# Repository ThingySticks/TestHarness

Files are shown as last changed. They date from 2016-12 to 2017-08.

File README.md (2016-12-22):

ThingySticks Test Harness
=========================

Particle Electron based test harness to test Photon based ThingyStick sticks.
Most pins of the Photon are taken to the Electron's matching pin (except VIn,  VBatt and RST).
e.g. D7 on Photon board Pogo Pins will connect to D7 on the Electron.

Board Under Test location is intended to be populated with Pogo pins or another connector system to match up with the Board Under Tests photon pads/socket.

Board under Test should not have a photon fitted.

Electron Pinout: https://docs.particle.io/assets/images/electron/illustrations/electron_pinout.pdf

Improvements for V2.1
---------------------

* 10k Pull down resistors for Q1 and Q2 relay drive FETs to prevent them oscilating when not connected.
* Add a button to start the test (e.g. Use C4).
* Add high side current monitor so PCB can be tested for shorts.
* Make use of I2C(2) on the Electrons C4/C5 pins (needs VIn relay to be driven from a different pin - maybe C0 - with a jumper so it can be disabled).
** Use full for current monitor
* B5,4 or 3 to measure voltage at VIn so that the USB power connection can be simulated (low priority).
* Diode on VIn from Electron so we don't try and power the relays and back feed the 5V regulator when running on USB or battery only.

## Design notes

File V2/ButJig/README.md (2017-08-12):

Cura Settings:

Profile: Fast Print

Modified as...
Layer Height: 0.2mm
Infil: 12
Adhesion: Skirt

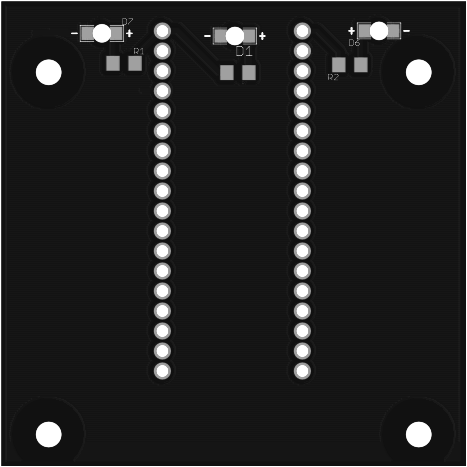
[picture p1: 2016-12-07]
V2/Images/TopBoard-bottom.png

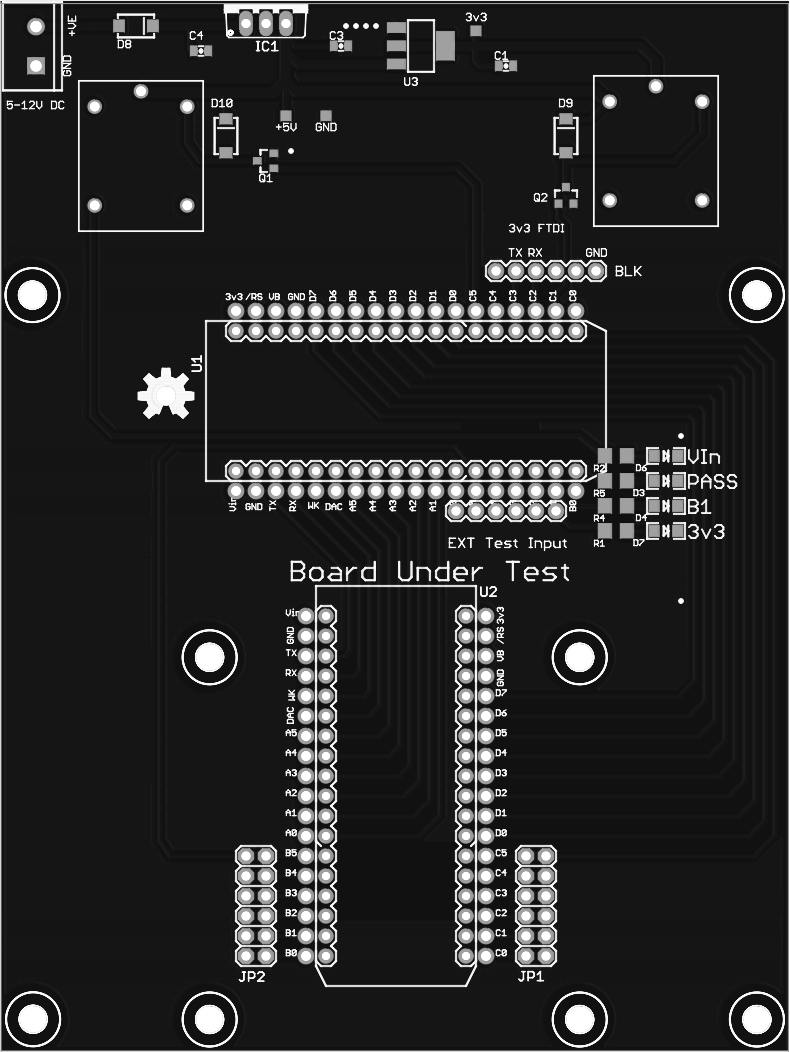
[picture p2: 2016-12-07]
V2/Images/BaseBoard-top.png

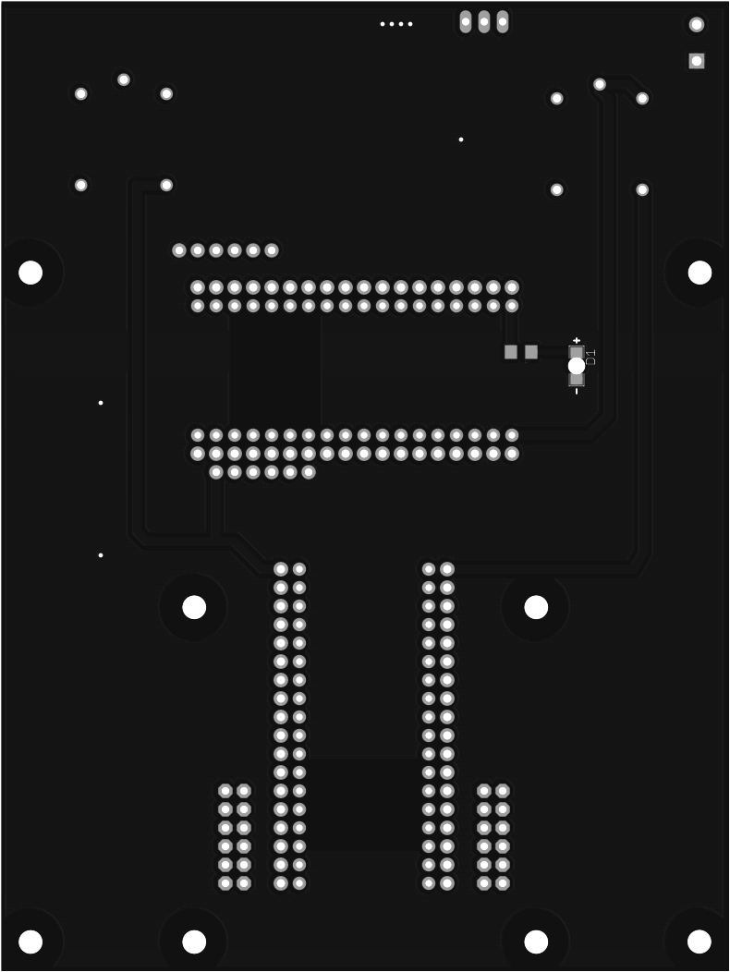
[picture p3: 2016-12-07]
V2/Images/BaseBoard-bottom.png

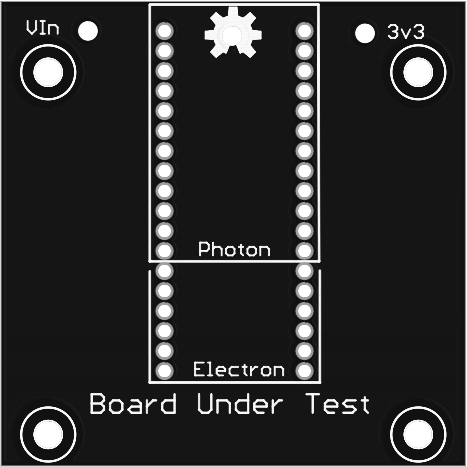
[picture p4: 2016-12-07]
V2/Images/TopBoard-top.png

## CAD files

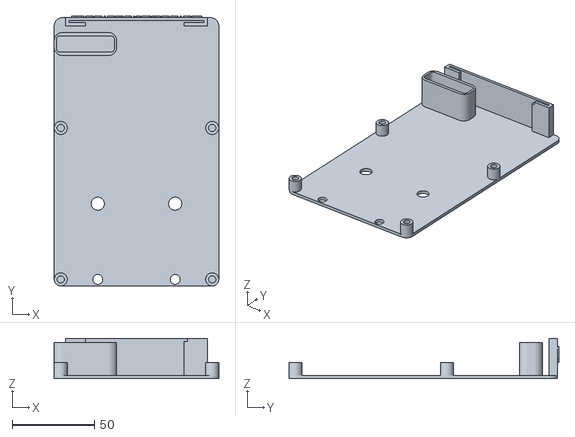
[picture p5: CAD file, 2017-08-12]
V2/ButJig/Base/JigBase.stl
100.0 x 164.0 x 24.4

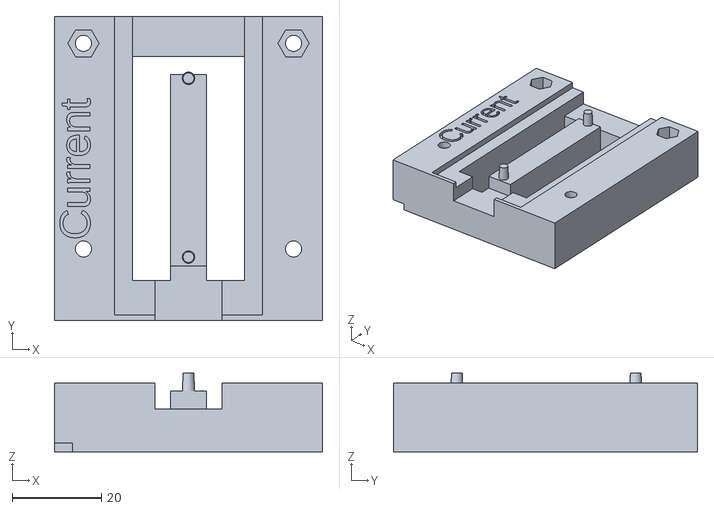
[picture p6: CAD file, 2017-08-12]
V2/ButJig/CurrentMonitor-Base.stl
60.0 x 68.0 x 17.6

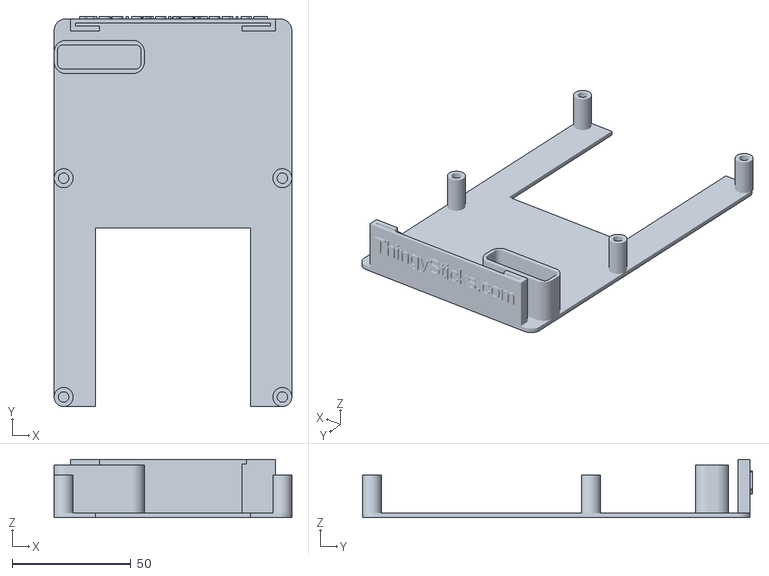
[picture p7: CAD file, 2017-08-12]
V2/ButJig/Base/JigBase-UnderMountingBoard.stl
100.0 x 164.0 x 24.4

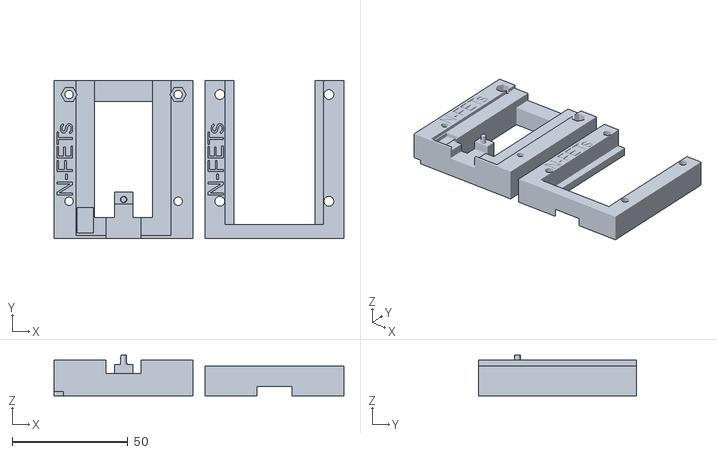
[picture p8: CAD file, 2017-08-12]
V2/ButJig/Quad-N-Fets.stl
125.0 x 68.0 x 17.6

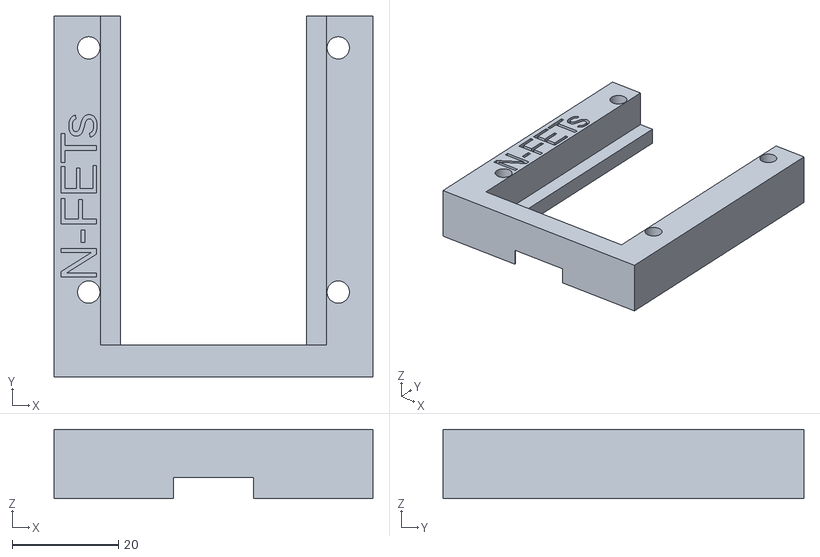
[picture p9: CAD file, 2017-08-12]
V2/ButJig/Quad-N-Fets-PushDown.stl
60.0 x 68.0 x 13.0

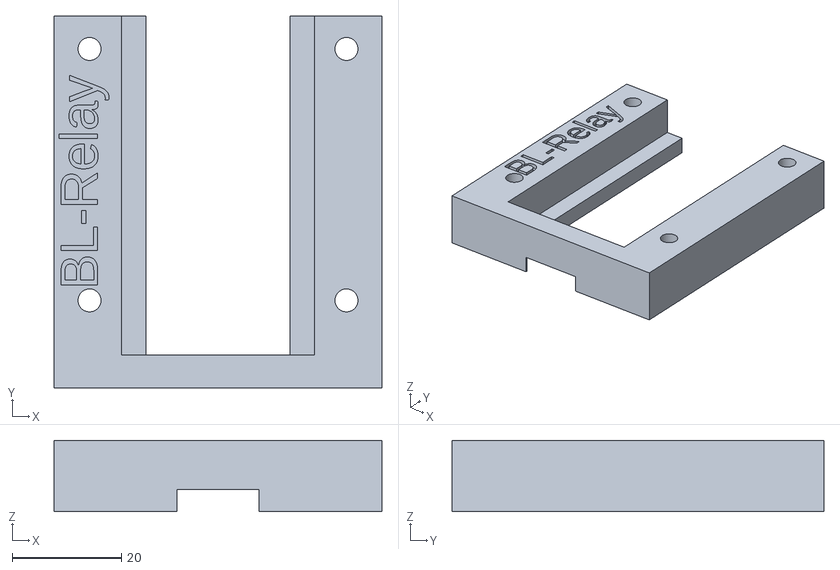
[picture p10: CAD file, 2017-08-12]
V2/ButJig/BigLatchingRelay-PushDown.stl
60.0 x 68.0 x 13.0

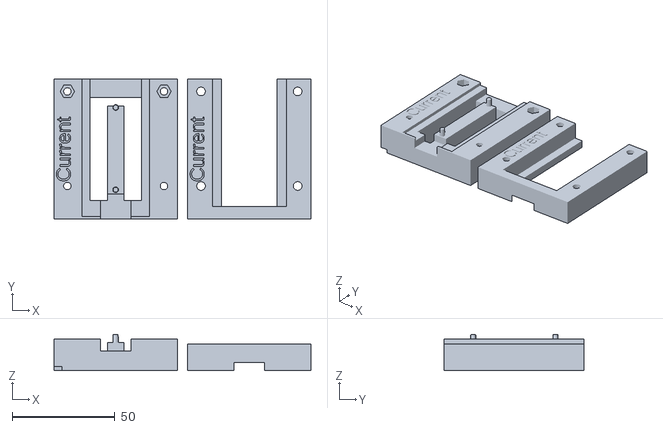
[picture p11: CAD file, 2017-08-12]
V2/ButJig/CurrentMonitor.stl
125.0 x 68.0 x 17.6

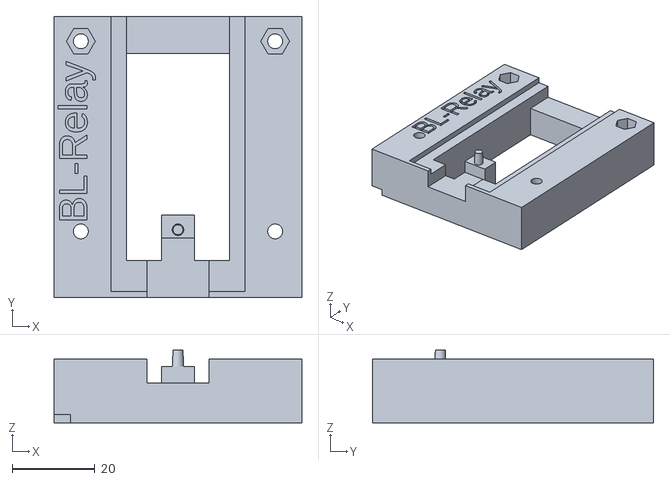
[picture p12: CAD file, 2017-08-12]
V2/ButJig/BigLatchingRelay-Base.stl
60.0 x 68.0 x 17.6

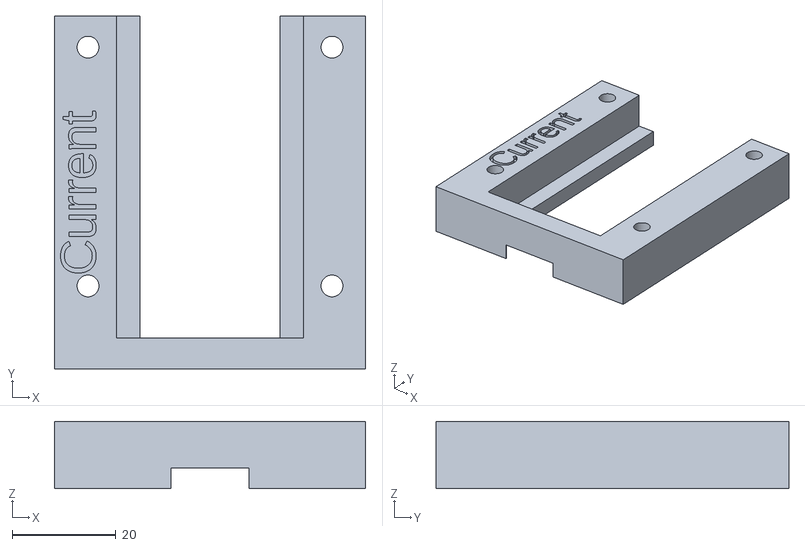
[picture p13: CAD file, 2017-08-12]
V2/ButJig/CurrentMonitor-PushDown.stl
60.0 x 68.0 x 13.0

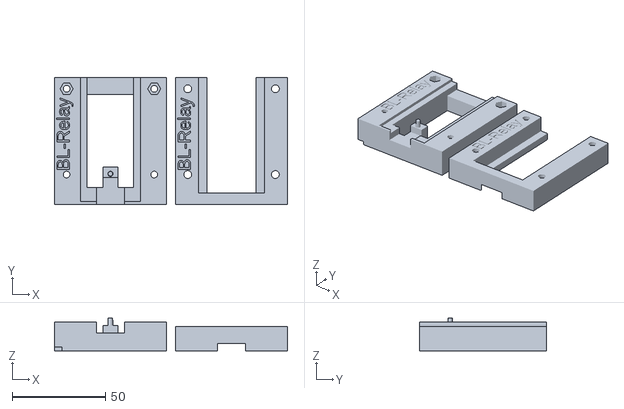
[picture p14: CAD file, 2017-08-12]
V2/ButJig/BigLatchingRelay.stl
125.0 x 68.0 x 17.6

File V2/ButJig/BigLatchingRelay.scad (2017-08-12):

buildBase = true;
buildPushDown = true;
showModels = true;

////////////////////////////////////////////////////////////////////
// Thermocouple PCB
// -----------------------------------------------------------------
// Device under test properties.
pin1ToPcbEdge =  8.3;
pcbPinOffset = 13.96;
pcbPin2Offset = 13.96;
pcbWidth = 31.31; //mm
pcbLength = 99.04;
pcbSupportBarLength = 20;
textLabel = "BL-Relay";

// TODO: Change this for the actual position.
oshLedXCutout = 0;
oshLedYCutout = 0; 
oshLedLength = 0;  // y axis.
oshLedWidth = 0; 
oshLedDepth = 0; 

showThermocouplePcb = true;
showQuadFetsPcb = false;
showEnvironmentV2Pcb = false;

include <ButJig.scad>;

module buildModel() {
    // Pcb
    cube([31.31,99.04,1.6]);
    
    // Move to the middle of the PCB.
    // Move down slightly to bring the markers though 
    // the 
    translate([31.31/2, 0, -4]) {
        // Mount pin 1
        translate([0,13.96,0]) {
            cylinder(d=3, h=20);
        }
        
        // Mount pin 2
        translate([0, 13.96,0]) {
            cylinder(d=3, h=20);
        }
        
        // Pin 1 marker.
        translate([8.89,8.3,0]) {
            cylinder(d=1, h=10);
        }
        
        // USB Plug
        // Z should be at the bottom of the PCB (1.6mm thick)
        // X is 1/2 width back from center
        // y is 15 back and 5 onto PCB
        translate([-(12/2),-15 + 5,4 - 1.6]) {
            cube([12, 20, 5]);
        }
    }
}

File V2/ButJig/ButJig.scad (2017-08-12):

// Base class for all the test jigs

// Critical measurements:
// Top left mount hole (with DUT vertical) is key alignment hole.
// Pin 1 X Offset from key hole = 14.78mm
// Pin 1 Y offset from key hole = 5.25mm (towards 0)
 
$fn=80;
cubeWidth = 60;
// Max length to make the cube.
// PCB may go past the end of it.
cubeLength = 68; //68;
bodyHeight = 18;


// FIXED (due to Pogo pins height).
// PCB needs to be at 13.5mm high for the pogo pins to make best contact.
pcbZPosition = 13.6;

// Make it a little higher so that the PCB can 
// be pressed level with the jig top
// but keep the POGO pins slightly compressed
bodyHeight = 15.4; // pcbZPosition + 1.6; // PCB depth


// Fixed. the Y distance from pin 1 Pogo pin to the first 
// mounting hole for the jig.
// How far infront of Pin1 the mounting hole is.
// Thsi should never change (pin 1 and mounting block hole never move).
// How far infront of Pin1 the mounting hole is.
pin1ToMountingHoleDistance =  5.25;

usbPlugWidth = 15;

// Mounting holes for us are 47mm across.
// 60 - 47 = 13 
// 13/2 = 6.5
holesXOffset = (60-47) / 2;
// How far down the block the mounting holes for the block are.
// 16mm is about the maximum that can be used without modifying the mounting block.
holesYOffset = 16; // 16mm gap between ext test input and top hole.

// The position of pin one on the test fixture
// this is constant
pin1Position = holesYOffset - pin1ToMountingHoleDistance;  

////////////////////////////////////////////////////////////////////
// Test Fixture properties.
// Board specific
////////////////////////////////////////////////////////////////////
// Will be in subclass file

/////////////////////////////////////////////////////////////////////
// Position of the PCB front edge
// Computed from the specified distance of pin 1 to the pcb edge.
frontEdgePosition = pin1Position - pin1ToPcbEdge;
echo ("frontEdgePosition:", frontEdgePosition);

/////////////////////////////////////////////////////////////////////

// Cut out for the 3v3 resistor on the test rig PCB
module boardResistorCutout() {
    cube([4,4,2]);
}

// block mounting hole is holesYOffset mm from the front edge.
module pcbCutout() {
        
// Work back from the computed Pin 1 Position to find where the 
// edge of the PCB should be.
xOffset = (cubeWidth - pcbWidth)/2;

    // add 2mm tollerance to the front/rear position of the PCB
    // as the finish may be rough and mounting pins are the most critical
    // And add 0.5mm either size for PCB width tollerance
    translate([xOffset-0.5, frontEdgePosition -1 , pcbZPosition]) {
       cube([pcbWidth+1, pcbLength + 2, bodyHeight - pcbZPosition + 0.01]);
    }
    
    // OSH LED on Thermocouple PCB
    translate([xOffset + oshLedXCutout, 
    frontEdgePosition + oshLedYCutout, 
    pcbZPosition-oshLedDepth]) {
        cube([oshLedWidth, oshLedLength, oshLedDepth+0.1]);
    }
    
    // Cutout at the end
    leftCutout = (cubeWidth - 25)/2;
    translate([leftCutout, 55, pcbZPosition -4]) {
        cube([25, cubeLength-55+0.1, 4.1]);
    }
}

// block mounting hole is holesYOffset mm from the front edge.
module pcbPin(offset) {
    
xOffset = (cubeWidth /2);
yPosition = frontEdgePosition + offset;
    
echo ("Offset:", offset);
echo ("yPosition:",yPosition);
echo ("pcbZPosition:",pcbZPosition);
    
    translate([xOffset, yPosition, pcbZPosition]) {
        cylinder(d1=2.8, d2=2.4, h=4);
    }
}

// Cut out a section to allow for a USB plug to have
// been soldered to the PCB.
module usbConnectorCutout() {
    
echo("USB pcbPinOffset: ", pcbPinOffset);
pinPosition = frontEdgePosition + pcbPinOffset;
    
    translate([(cubeWidth - usbPlugWidth)/2, 0, pcbZPosition-4]) {
        // Go most of the way to the first PCB pin.
        cube([usbPlugWidth, pinPosition -2, 8]);
    }
}

module pogoPinsCutout() {
    cube([25, 50, 20]);
}

module mountHole(x,y, nutUnder, nutOnTop, holeDiameter) {
nutHoleDiameter = 7;
    translate([x,y,0]) {
        
        // Hollow out the main screw thread all the way up.
        translate([0,0,-0.1]) {
            cylinder(d=holeDiameter, h=bodyHeight+2);
        }
            
        // If their is a nut underneath this (i.e. screw fixed to PCB)
        if (nutUnder) {
            cylinder(d=nutHoleDiameter, h=4);
        
            translate([0,0,4]) {
                cylinder(d1=nutHoleDiameter,d2=holeDiameter, h=10);
            }
        }
        
        if (nutOnTop) {
            translate([0,0,bodyHeight - 4]) {
                // Make it hex to hold the nut
                cylinder(d=7, h=4 + 0.3, $fn=6);
            }
        }
    }
}

module mountHoles() {
    // Across = 47mm.
    // Down = 46mm.
    
holeDiameter = 3.6;
    
    
    mountHole(0,0, true, false, holeDiameter);
    // This pin is key pin with 0 offset all around?
    mountHole(47,0, true, false, holeDiameter);
    mountHole(0,46, false, true, holeDiameter);
    mountHole(47,46, false, true, holeDiameter);
}


module addText(zPosition, height) {
    translate([8,18,zPosition]) {
        rotate([0,0,90]) {
            linear_extrude(h=height) {
                #text(textLabel, size=7);
            }
        }
    }
}

module mainBody(holesXOffset) {
    difference() {
        union() {
            color("blue") {
                cube([cubeWidth, cubeLength, bodyHeight]);
            }
        }
        union() {
            // Move 5 + (4/2) mm down for the hole.
            translate([holesXOffset,holesYOffset,-0.1]) {
                mountHoles();
            }
            
            // 14mm wide. so 7mm back from center.
            translate([30-(25/2),holesYOffset - 7,-0.1]) {
                pogoPinsCutout();
            }
            
            pcbCutout(holesYOffset);
            
            // 0,0 position their is a resistor on the main
            // PCB (for 3v3 LED), need to nibble out a little from that corner
            // to prevent it clashing
            boardResistorCutout();
            
            addText(bodyHeight-1, 1);            
        }
    }
}

module body() {
   
// Pin 1 is 5.25mm from (top hole?) - smaller y.
    // pin1ToMountingHoleDistance
    
    // show pin 1
    translate([47 + holesXOffset - 14.78 ,holesYOffset  - pin1ToMountingHoleDistance,0]) {
       // cylinder(d=1, h=15);
    }
    
    
    difference() {
        union() {
            mainBody(holesXOffset);
            // Fill in the middle bit to allow for a support pin
            translate([(cubeWidth / 2) -4, 0, 0]) {
                color("green") {
                    cube([8, pcbSupportBarLength, pcbZPosition]);
                }
            }
        } 
        union() {
            usbConnectorCutout();
        }
    }
    
    // Add a vertical pin to locate the PCB onto the jig.
    pcbPin(pcbPinOffset);
    // Some boards have a second pin.
    pcbPin(pcbPin2Offset);
    
    translate([0,0,0]) {
        // pin1Marker();
    }
}

module pressDownTool() {
    
height = 13; // Should just cover full height of the bolts
holesXOffset = (60-47) / 2;
// How far down the block the mounting holes for the block are.
// 16mm is about the maximum that can be used without modifying the mounting block.
holesYOffset = 16; // 16mm gap between ext test input and top hole.
holeDiameter = 4.2; // larger than the base
    
    difference() {
        union() {
            color("pink") {
                cube([cubeWidth, cubeLength, height]);
            }
        }
        union() {
            addText(height-1, 1);
            
            translate([holesXOffset,holesYOffset,-0.1]) {
                    mountHole(0,0, false, false, holeDiameter);
                    // This pin is key pin with 0 offset all around?
                    mountHole(47,0, false, false, holeDiameter);
                    mountHole(0,46, false, false, holeDiameter);
                    mountHole(47,46, false, false, holeDiameter);
            }
            
            // Cut out the entire inside for pcb - 5mm (2.5mm either size)
            
             
            // The position of pin one on the test fixture
            // this is constant
            pin1Position = holesYOffset - pin1ToMountingHoleDistance;    

            // Work back from the computed Pin 1 Position to find where the 
            // edge of the PCB should be.
            frontEdgePosition = pin1Position - pin1ToPcbEdge;
            xOffset = (cubeWidth - pcbWidth)/2;
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

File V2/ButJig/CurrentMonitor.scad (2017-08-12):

buildBase = true;
buildPushDown = true;
showModels = true;

////////////////////////////////////////////////////////////////////
// Environment V2
// -----------------------------------------------------------------
// Device under test properties.
pin1ToPcbEdge =  8.57;
pcbPinOffset = 12.00;
pcbPin2Offset = 52.00;
pcbWidth = 32; // 31.75; //mm on X Axis.
pcbLength = 90; // on Y Axis.
// Lenfth of the middle bar with the pins on
pcbSupportBarLength = 55;
textLabel = "Current";

oshLedXCutout = 0;
oshLedYCutout = 0; 
oshLedLength = 11;  // y axis.
oshLedWidth = 7; 
oshLedDepth = 0; 

include <ButJig.scad>;


module buildModel() {
    // Pcb
    // Don't use variables above as they may need to be 
    // fudged to give suitable tollerances.
    cube([32,90,1.6]);
    
    // Move to the middle of the PCB.
    // Move down slightly to bring the markers though 
    // the 
    translate([32/2, 0,-4]) {
        // First mounting hole
        translate([0,12,0]) {
            cylinder(d=3, h=20);
        }
        
        // Second mounting hole
        translate([0, 12+40,0]) {
            cylinder(d=3, h=20);
        }
        
        // Pin 1 marker.
        translate([7,8.57,0]) {
            cylinder(d=1, h=10);
        }
        
        // USB Plug
        // Z should be at the bottom of the PCB (1.6mm thick)
        // X is 1/2 width back from center
        // y is 15 back and 5 onto PCB
        translate([-(12/2),-15 + 5,4 - 1.6]) {
            cube([12, 20, 5]);
        }
    }
}

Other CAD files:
V2/ButJig/EnvironmentV2-Base.stl
V2/ButJig/Thermocouple.stl
V2/ButJig/EnvironmentV2.stl
V2/ButJig/Thermocouple-Base.stl
V2/ButJig/Thermocouple-PushDown.stl
V2/ButJig/Quad-N-Fets-Base.stl
V2/ButJig/EnvironmentV2-PushDown.stl
V2/ButJig/EnvironmentV2.scad
V2/ButJig/Base/JigBase.scad
V2/ButJig/Quad-N-Fets.scad
V2/ButJig/Thermocouple.scad

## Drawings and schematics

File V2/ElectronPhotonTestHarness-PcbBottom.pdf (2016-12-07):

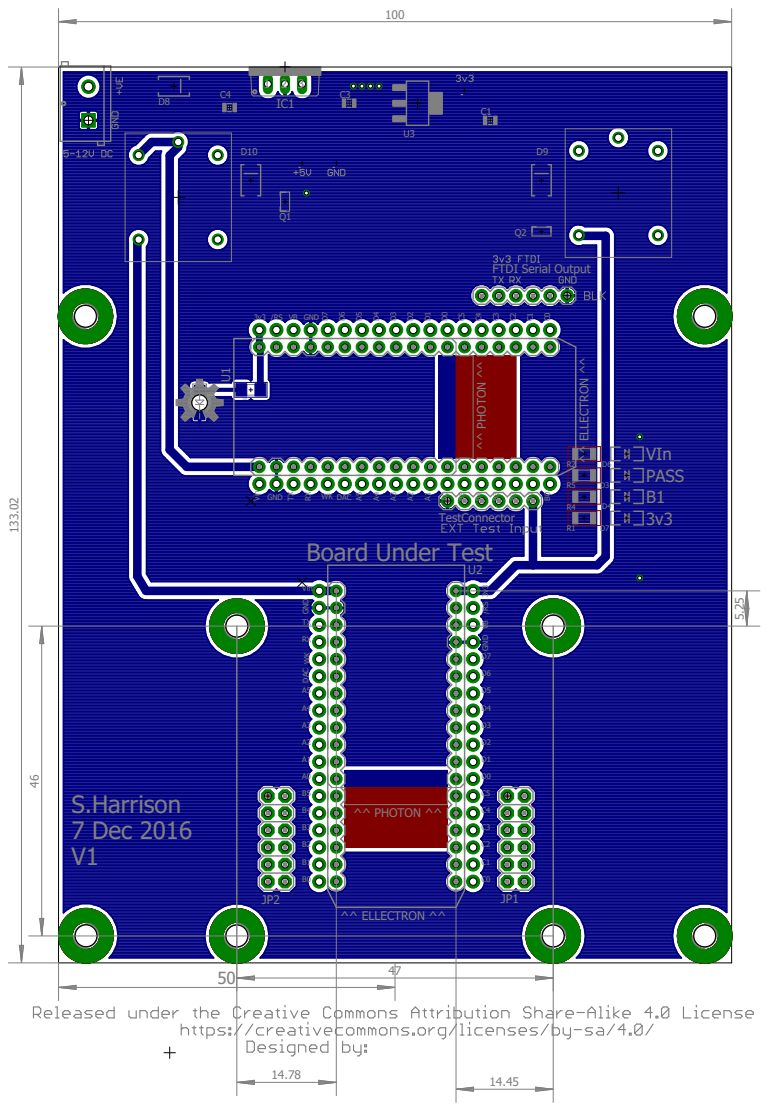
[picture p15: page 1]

VIn Board Under Test

R2R4R5 | PASS

TestConnector | 3v3

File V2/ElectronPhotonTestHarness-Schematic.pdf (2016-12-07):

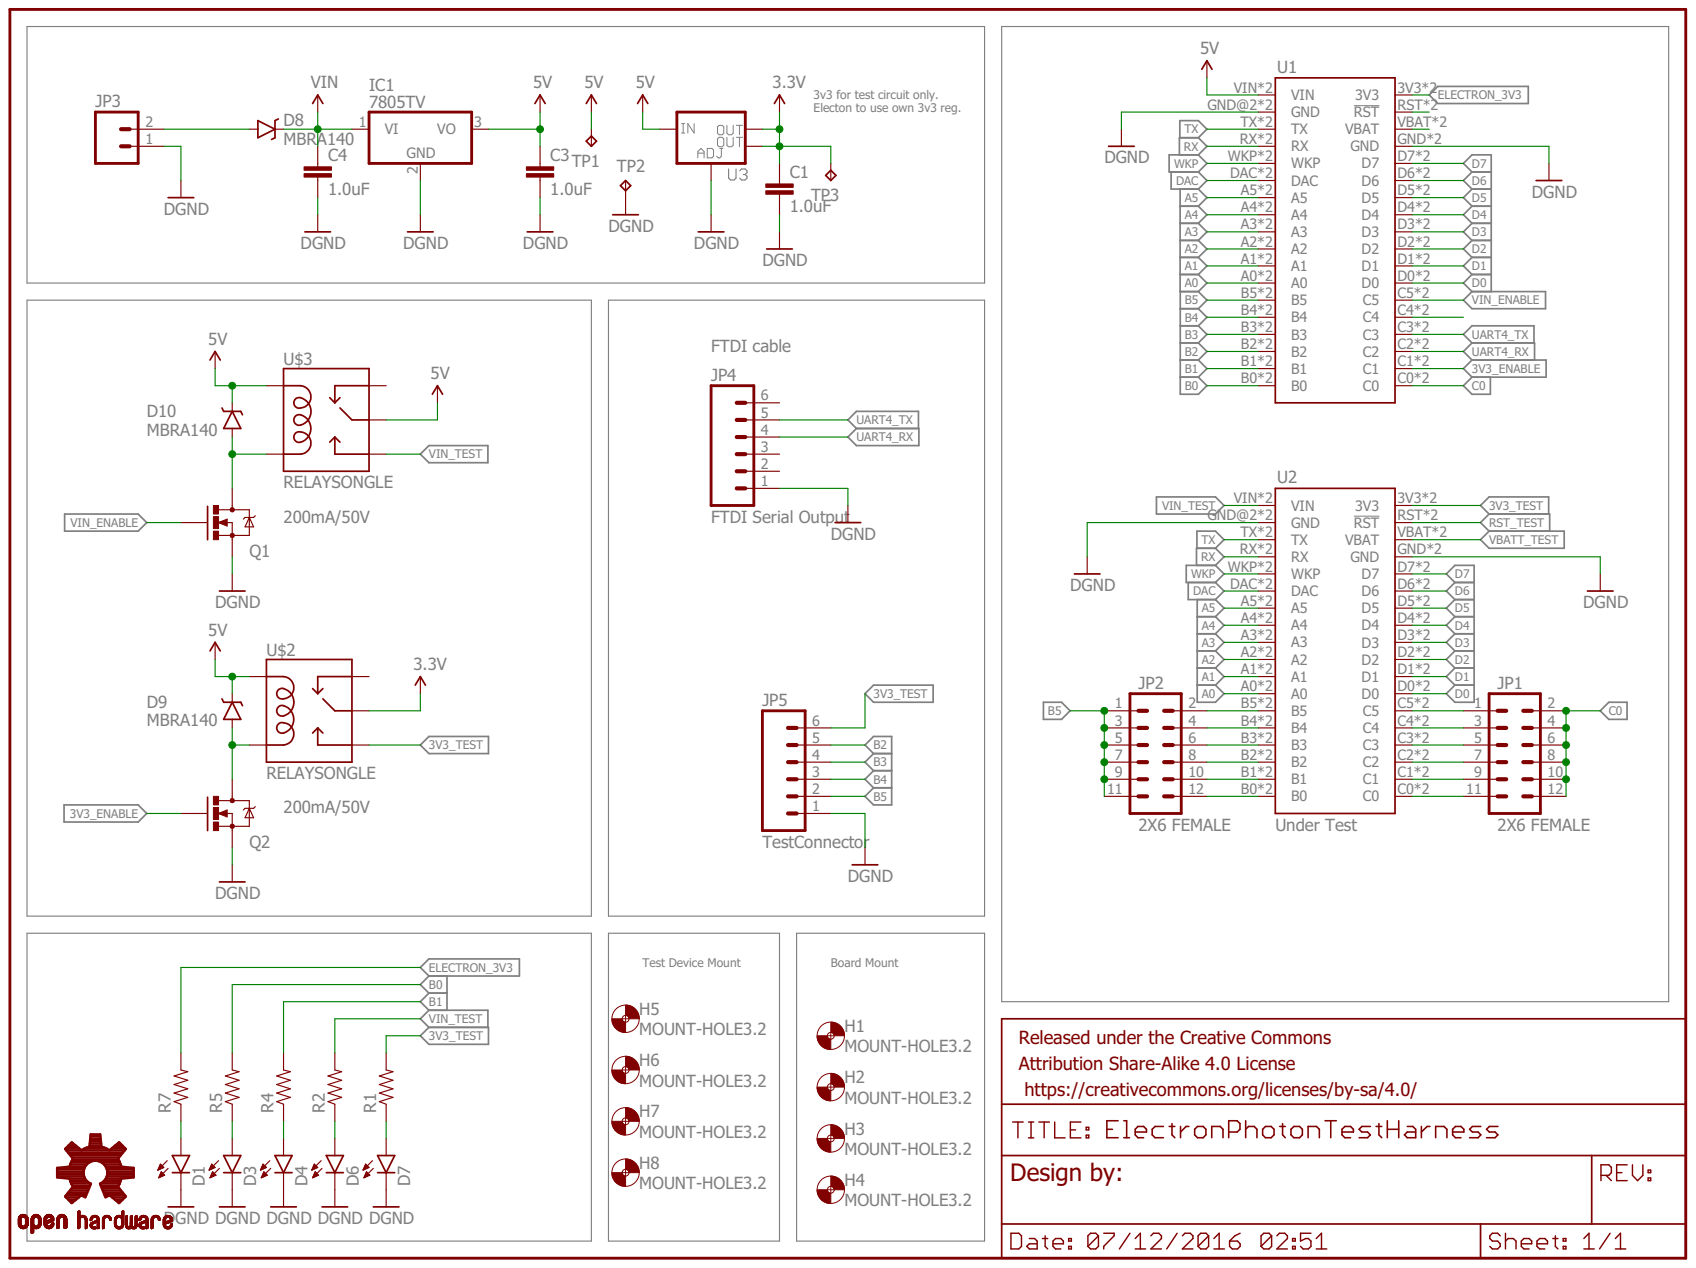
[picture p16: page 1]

3v3 for test circuit only. Electon to use own 3v3 reg.

DGND DGND DGND DGND DGND

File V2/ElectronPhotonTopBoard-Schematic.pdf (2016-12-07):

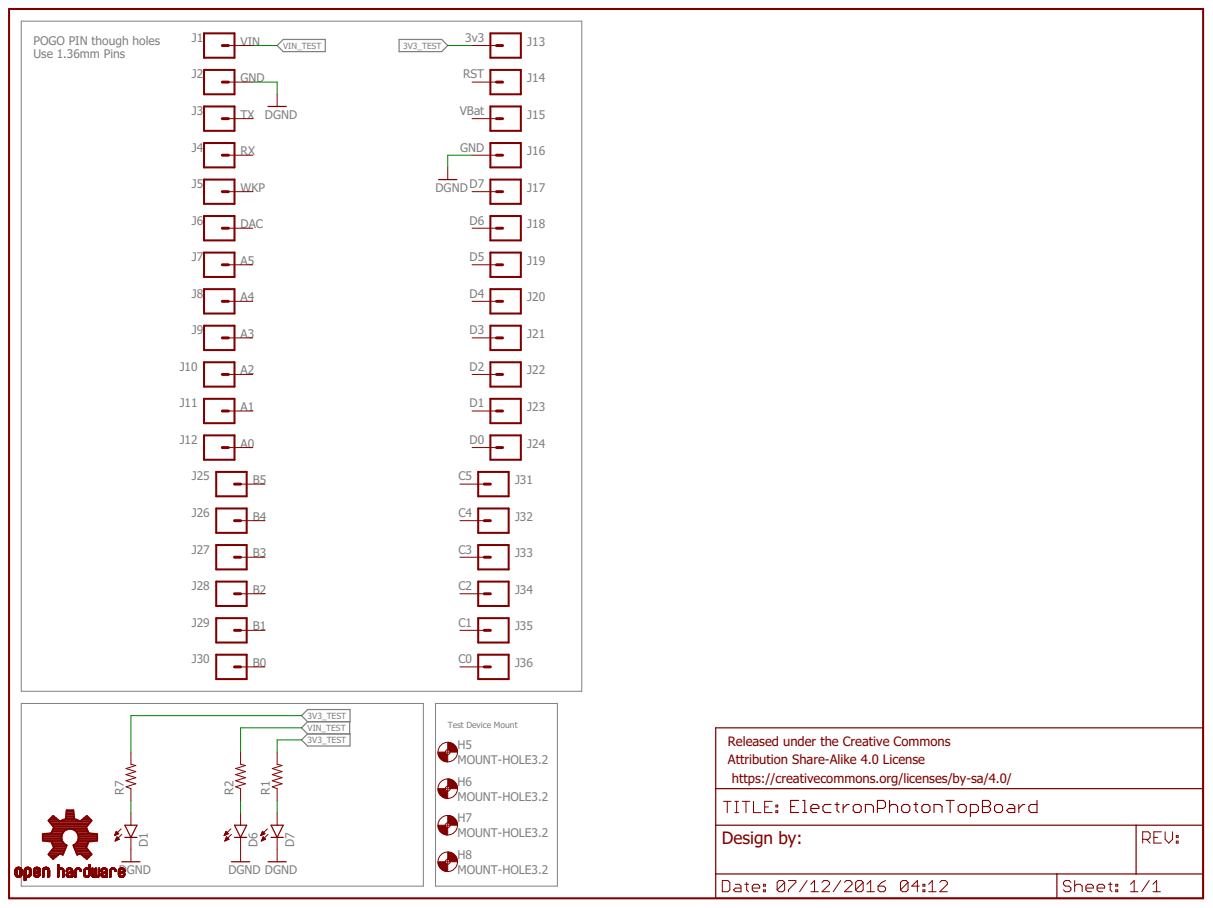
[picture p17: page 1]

POGO PIN though holes Use 1.36mm Pins

Released under the Creative Commons Attribution Share-Alike 4.0 License https://creativecommons.org/licenses/by-sa/4.0/

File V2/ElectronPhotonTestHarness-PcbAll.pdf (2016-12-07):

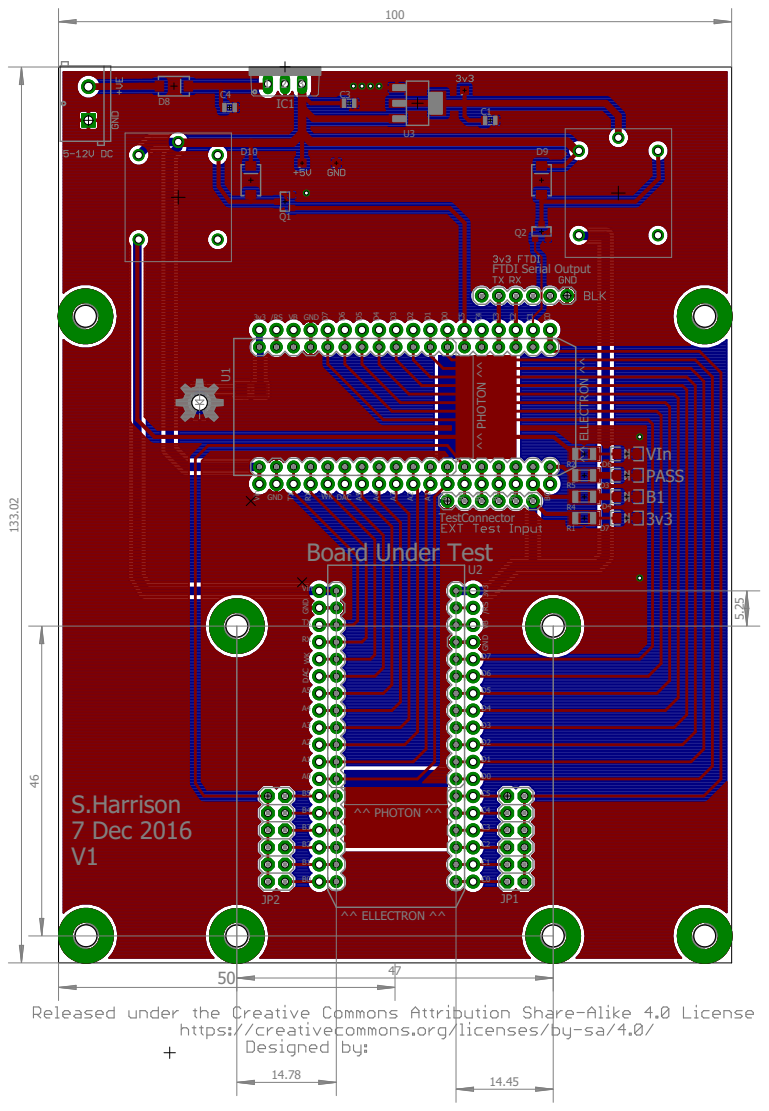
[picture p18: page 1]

FTDI Serial Output

PASS
B1

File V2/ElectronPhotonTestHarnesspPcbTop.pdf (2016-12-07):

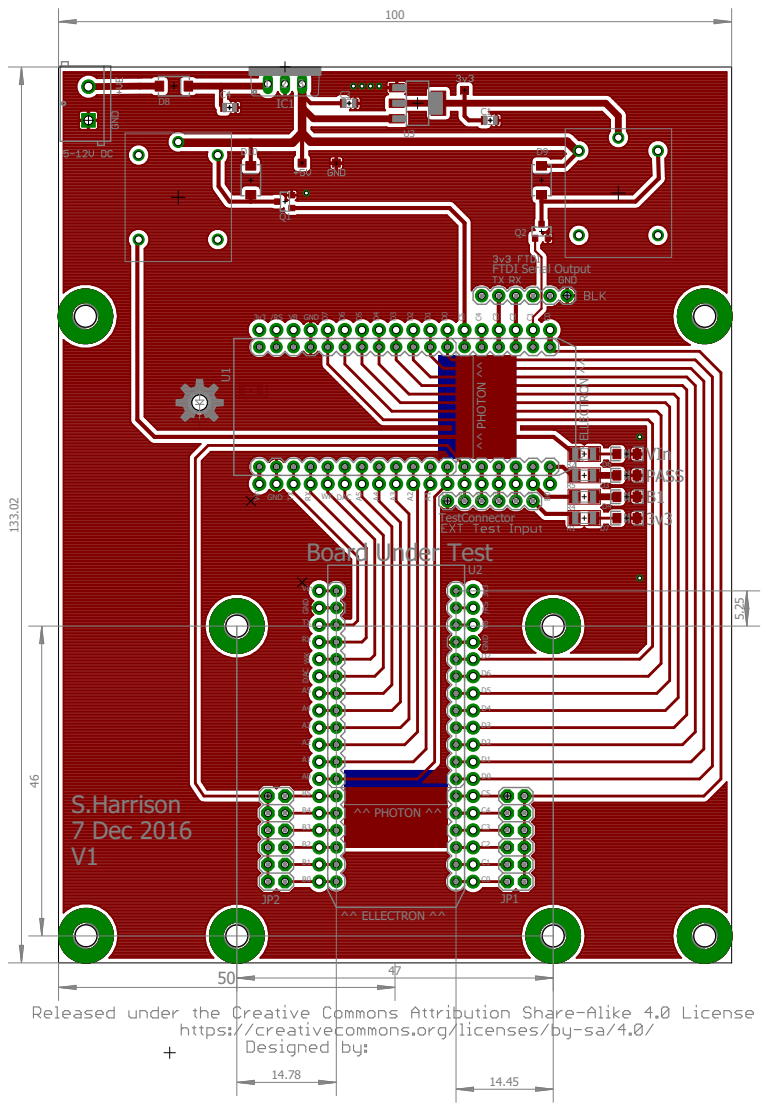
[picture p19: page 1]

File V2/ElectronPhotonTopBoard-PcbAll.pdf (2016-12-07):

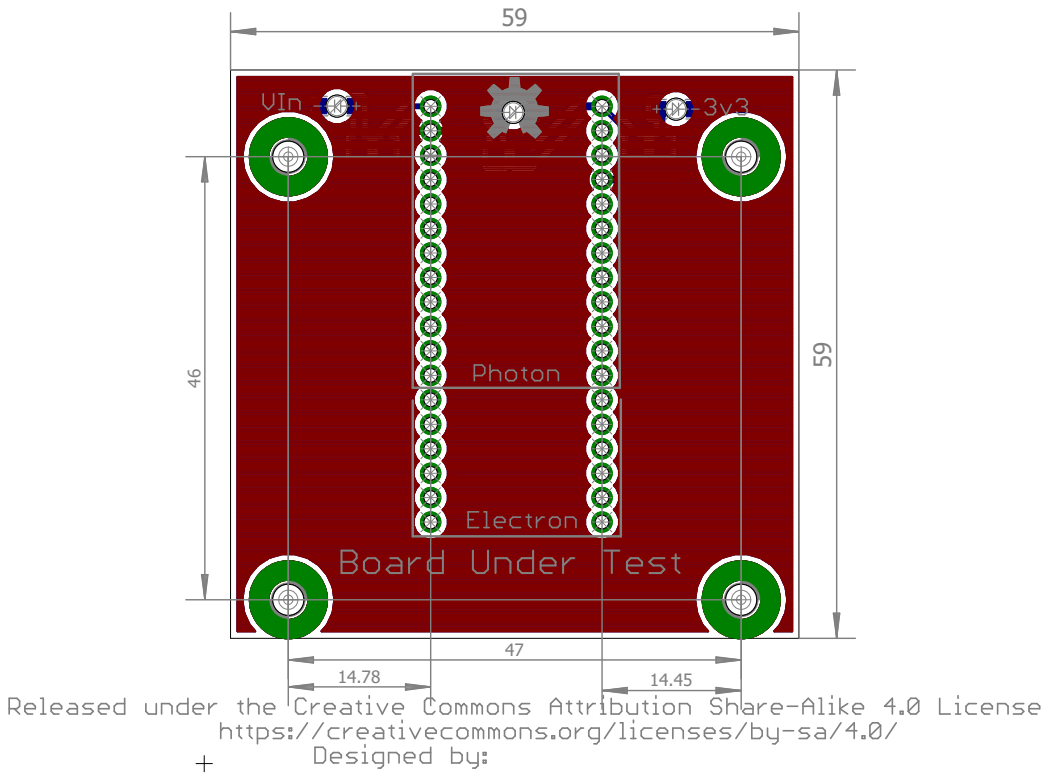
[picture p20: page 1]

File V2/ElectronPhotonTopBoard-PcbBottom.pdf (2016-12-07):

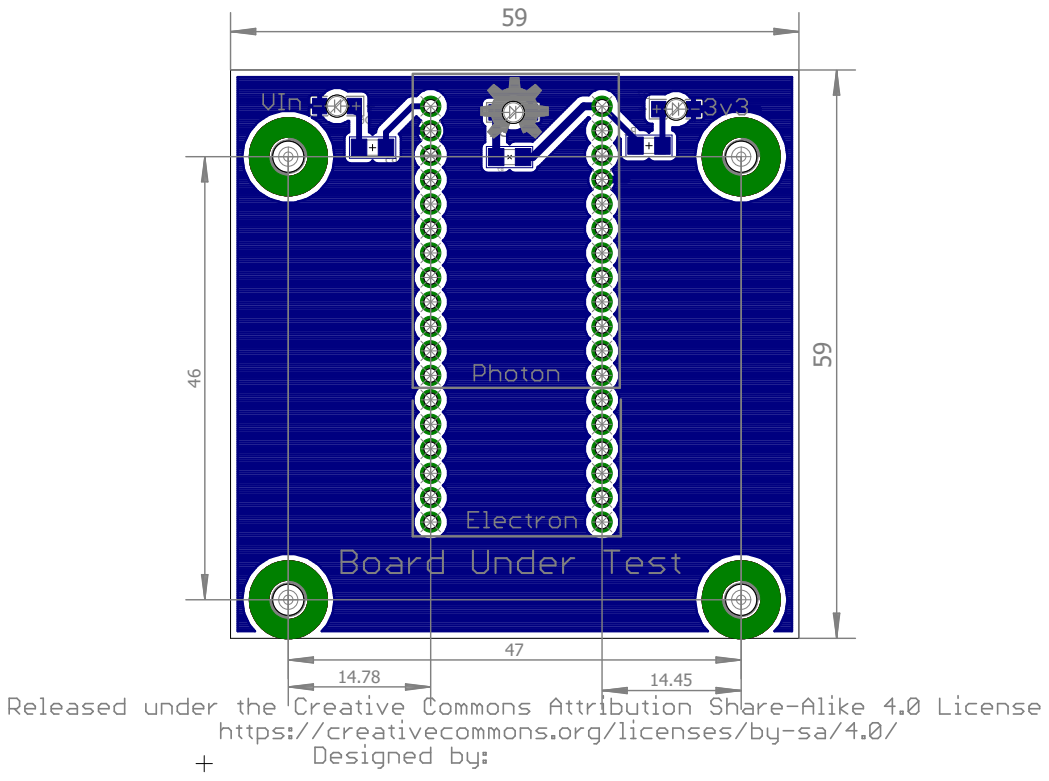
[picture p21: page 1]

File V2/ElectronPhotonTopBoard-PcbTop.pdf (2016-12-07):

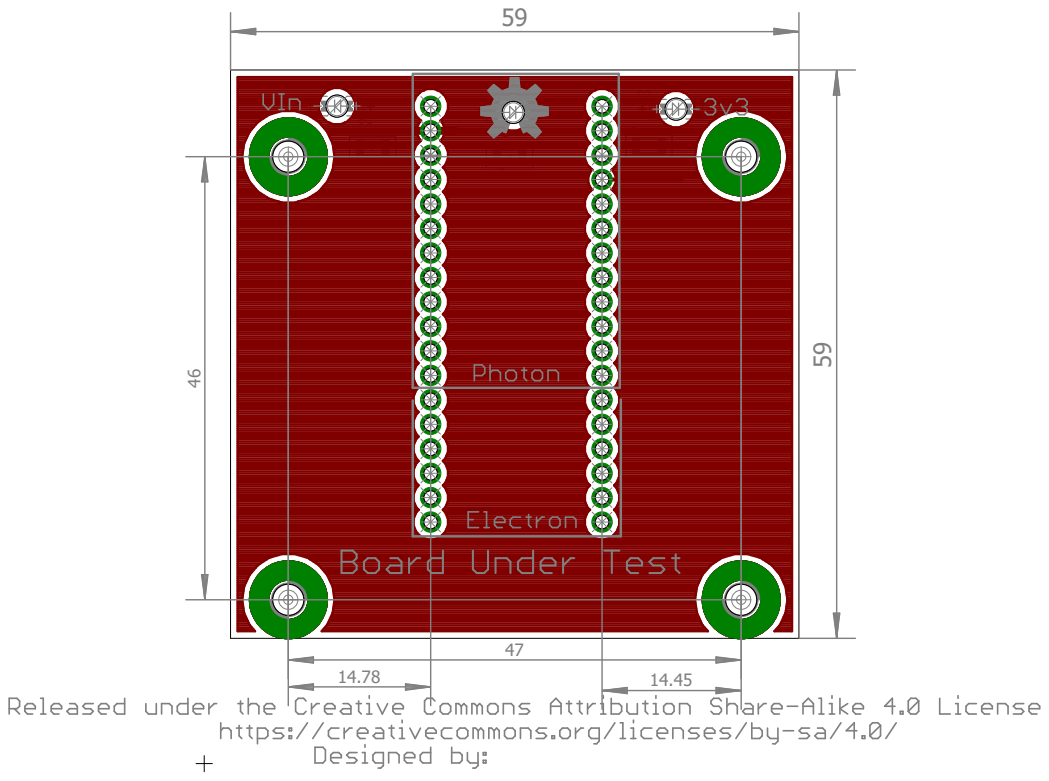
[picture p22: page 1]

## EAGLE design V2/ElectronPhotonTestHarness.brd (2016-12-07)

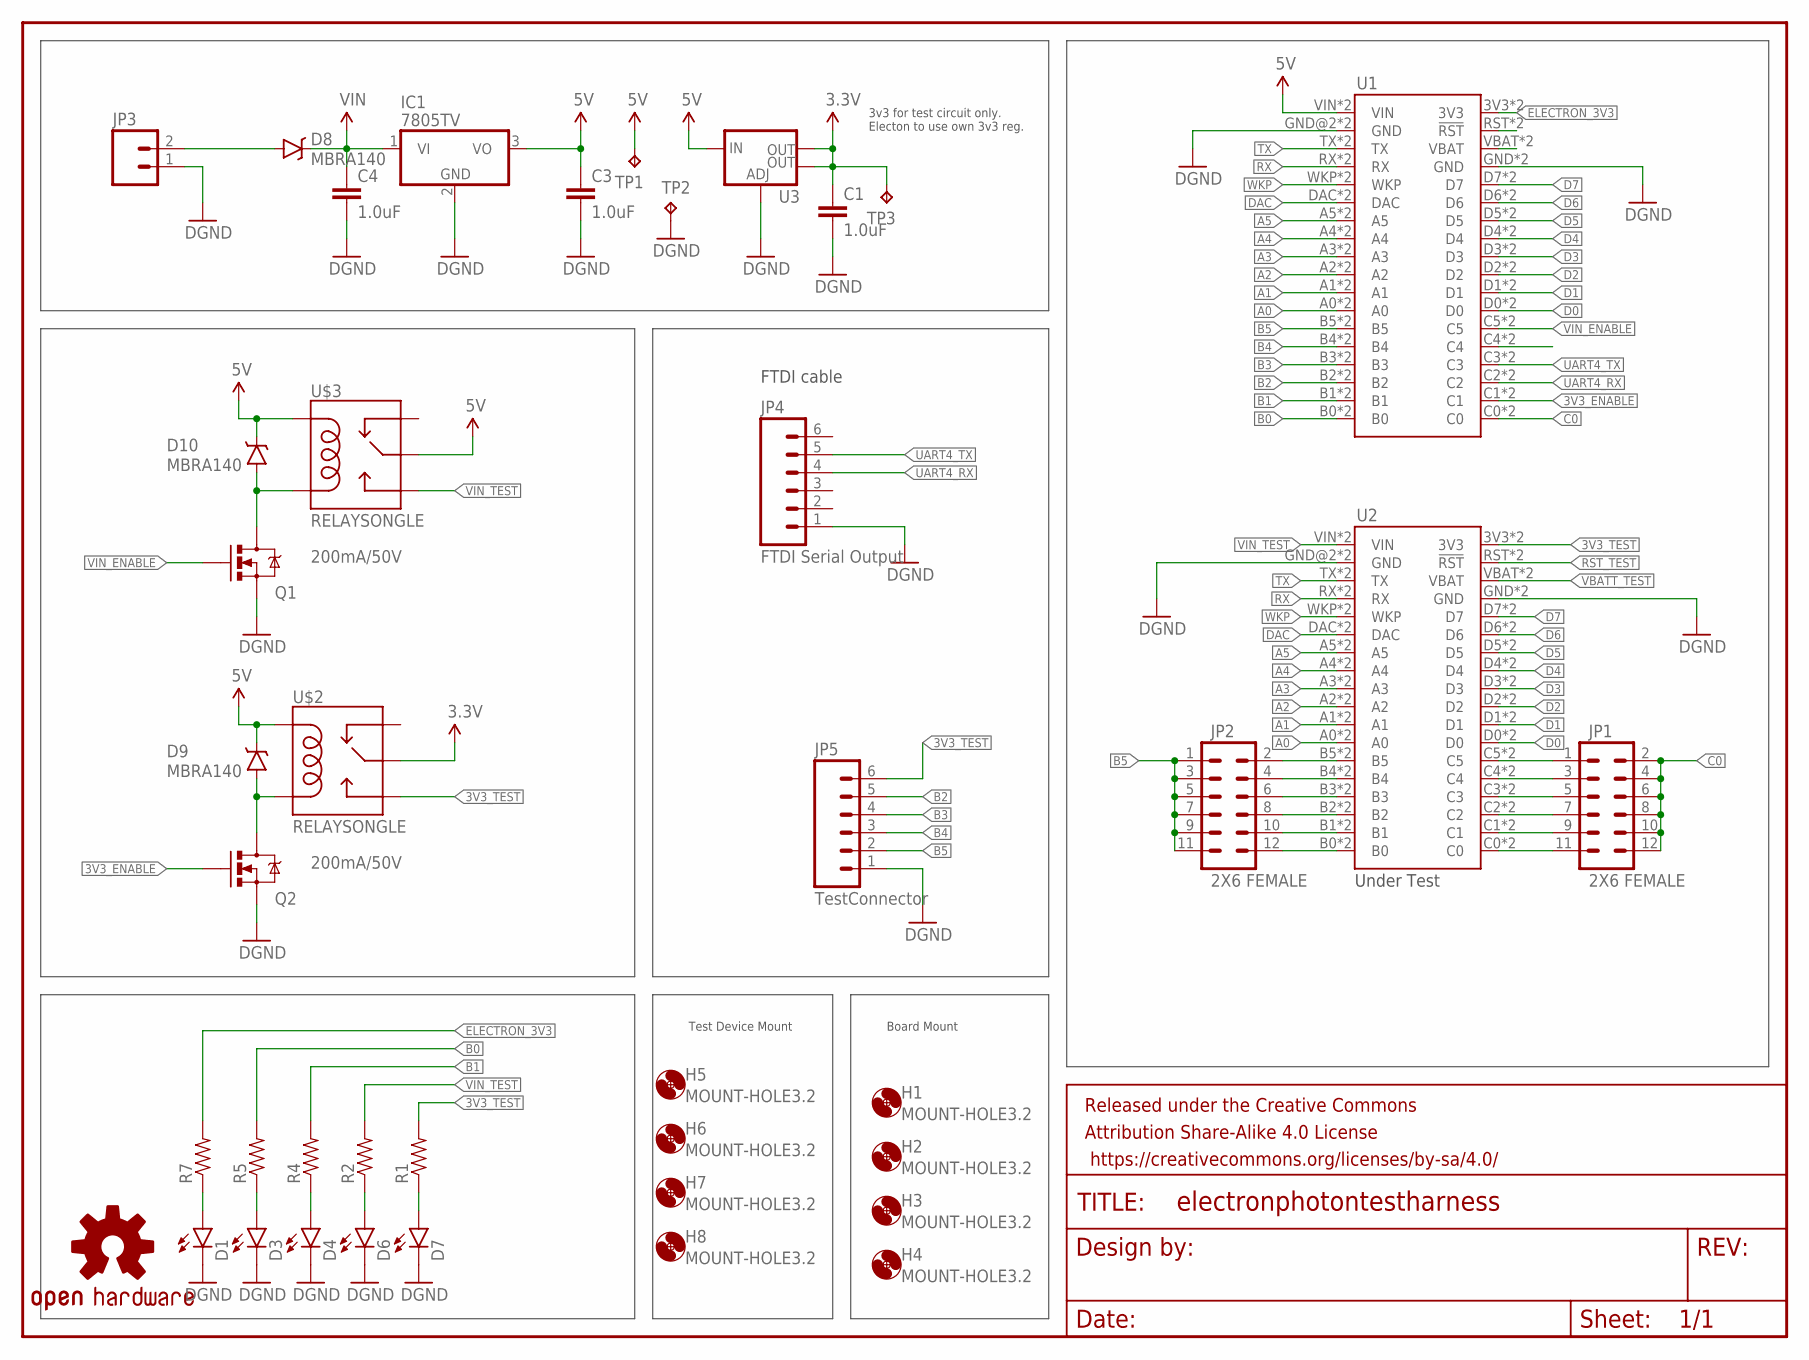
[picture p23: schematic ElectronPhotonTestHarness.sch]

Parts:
C1, C3, C4: 1.0uF; 0805-CAP
D1: LED1206-BOTTOM; LED-1206-BOTTOM
D3, D4, D6, D7: LED1206; LED-1206
D8, D9, D10: MBRA140; SMA-DIODE
FRAME1: FRAME-LETTER; CREATIVE_COMMONS
H1, H2, H3, H4, H5, H6, H7, H8: MOUNT-HOLE3.2; 3,2
IC1: 7805TV; TO220V
JP1, JP2: 2X6 FEMALE; 2X6
JP3: M025MM; SCREWTERMINAL-5MM-2
JP4: FTDI Serial Output; 1X06
JP5: TestConnector; 1X06
LOGO1: OSHW-LOGOL; OSHW-LOGO-L
Q1, Q2: 200mA/50V; SOT23-3
R1, R2, R4, R5, R7: RESISTOR1206; 1206
TP1, TP2, TP3: TPTP12SQ; TP12SQ
U1: ELECTRONDUALNAMED; ELECTRON_SIMPLE_SILK_NAMES_DUAL
U2: UnderTest; ELECTRON_SIMPLE_SILK_NAMES_DUAL
U3: V_REG_LM1117SOT223; SOT223
U$2, U$3: RELAYSONGLE; SRD-5VDC-SL-C

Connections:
3.3V: C1.1, TP3.TP, U3.2 (OUT), U3.4 (OUT), U$2.COMMON (MAIN)
3V3_ENABLE: Q2.1 (G), U1.C1, U1.C1_1 (C1)
3V3_TEST: JP5.6, R1.2, U2.3V3, U2.3V3_1 (3V3), U$2.OPEN (NO)
5V: C3.1, D9.C, D10.C, IC1.3 (VO), TP1.TP, U1.VIN, U1.VIN_1B (VIN), U3.3 (IN), U$2.COIL1, U$3.COIL1, U$3.COMMON (MAIN)
A0: U1.A0, U1.A0_1 (A0), U2.A0, U2.A0_1 (A0)
A1: U1.A1, U1.A1_1 (A1), U2.A1, U2.A1_1 (A1)
A2: U1.A2, U1.A2_1 (A2), U2.A2, U2.A2_1 (A2)
A3: U1.A3, U1.A3_1 (A3), U2.A3, U2.A3_1 (A3)
A4: U1.A4, U1.A4_1 (A4), U2.A4, U2.A4_1 (A4)
A5: U1.A5, U1.A5_1 (A5), U2.A5, U2.A5_1 (A5)
B0: R5.2, U1.B0, U1.B0_1 (B0)
B1: R4.2, U1.B1, U1.B1_1 (B1)
B2: JP5.5, U1.B2, U1.B2_1 (B2)
B3: JP5.4, U1.B3, U1.B3_1 (B3)
B4: JP5.3, U1.B4, U1.B4_1 (B4)
B5: JP2.1, JP2.3, JP2.5, JP2.7, JP2.9, JP2.11, JP5.2, U1.B5, U1.B5_1 (B5)
C0: JP1.2, JP1.4, JP1.6, JP1.8, JP1.10, JP1.12, U1.C0, U1.C0_1 (C0)
D0: U1.D0, U1.D0_1 (D0), U2.D0, U2.D0_1 (D0)
D1: U1.D1, U1.D1_1 (D1), U2.D1, U2.D1_1 (D1)
D2: U1.D2, U1.D2_1 (D2), U2.D2, U2.D2_1 (D2)
D3: U1.D3, U1.D3_1 (D3), U2.D3, U2.D3_1 (D3)
D4: U1.D4, U1.D4_1 (D4), U2.D4, U2.D4_1 (D4)
D5: U1.D5, U1.D5_1 (D5), U2.D5, U2.D5_1 (D5)
D6: U1.D6, U1.D6_1 (D6), U2.D6, U2.D6_1 (D6)
D7: U1.D7, U1.D7_1 (D7), U2.D7, U2.D7_1 (D7)
DAC: U1.DAC, U1.DAC_1 (DAC), U2.DAC, U2.DAC_1 (DAC)
ELECTRON_3V3: R7.2, U1.3V3, U1.3V3_1 (3V3)
GND: C1.2, C3.2, C4.2, D1.C, D3.C, D4.C, D6.C, D7.C, IC1.2 (GND), JP3.1, JP4.1, JP5.1, Q1.2 (S), Q2.2 (S), TP2.TP, U1.GND, U1.GND@2 (GND), U1.GND_1 (GND), U1.GND_1B (GND), U2.GND, U2.GND@2 (GND), U2.GND_1 (GND), U2.GND_1B (GND), U3.1 (ADJ)
unnamed: JP2.2, U2.B5, U2.B5_1 (B5)
unnamed: JP2.4, U2.B4, U2.B4_1 (B4)
unnamed: JP2.6, U2.B3, U2.B3_1 (B3)
unnamed: JP2.8, U2.B2, U2.B2_1 (B2)
unnamed: JP2.10, U2.B1, U2.B1_1 (B1)
unnamed: JP2.12, U2.B0, U2.B0_1 (B0)
unnamed: JP1.11, U2.C0, U2.C0_1 (C0)
unnamed: JP1.9, U2.C1, U2.C1_1 (C1)
unnamed: JP1.7, U2.C2, U2.C2_1 (C2)
unnamed: JP1.5, U2.C3, U2.C3_1 (C3)
unnamed: JP1.3, U2.C4, U2.C4_1 (C4)
unnamed: JP1.1, U2.C5, U2.C5_1 (C5)
unnamed: D1.A, R7.1
unnamed: U1.RST (!RST), U1.RST_1 (!RST)
unnamed: D3.A, R5.1
unnamed: D4.A, R4.1
unnamed: U1.VBAT, U1.VBATT_1 (VBAT)
unnamed: D6.A, R2.1
unnamed: D7.A, R1.1
unnamed: D8.A, JP3.2
unnamed: U1.C4, U1.C4_1 (C4)
RELAY_3V3: D9.A, Q2.3 (D), U$2.COIL2
RELAY_5V: D10.A, Q1.3 (D), U$3.COIL2
RST_TEST: U2.RST (!RST), U2.RST_1 (!RST)
RX: U1.RX, U1.RX_1 (RX), U2.RX, U2.RX_1 (RX)
TX: U1.TX, U1.TX_1 (TX), U2.TX, U2.TX_1 (TX)
UART4_RX: JP4.4, U1.C2, U1.C2_1 (C2)
UART4_TX: JP4.5, U1.C3, U1.C3_1 (C3)
VBATT_TEST: U2.VBAT, U2.VBATT_1 (VBAT)
VIN: C4.1, D8.C, IC1.1 (VI)
VIN_ENABLE: Q1.1 (G), U1.C5, U1.C5_1 (C5)
VIN_TEST: R2.2, U2.VIN, U2.VIN_1B (VIN), U$3.OPEN (NO)
WKP: U1.WKP, U1.WKP_1 (WKP), U2.WKP, U2.WKP_1 (WKP)

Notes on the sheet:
Under Test
3v3 for test circuit only. Electon to use own 3v3 reg.
FTDI cable
Test Device Mount
Board Mount

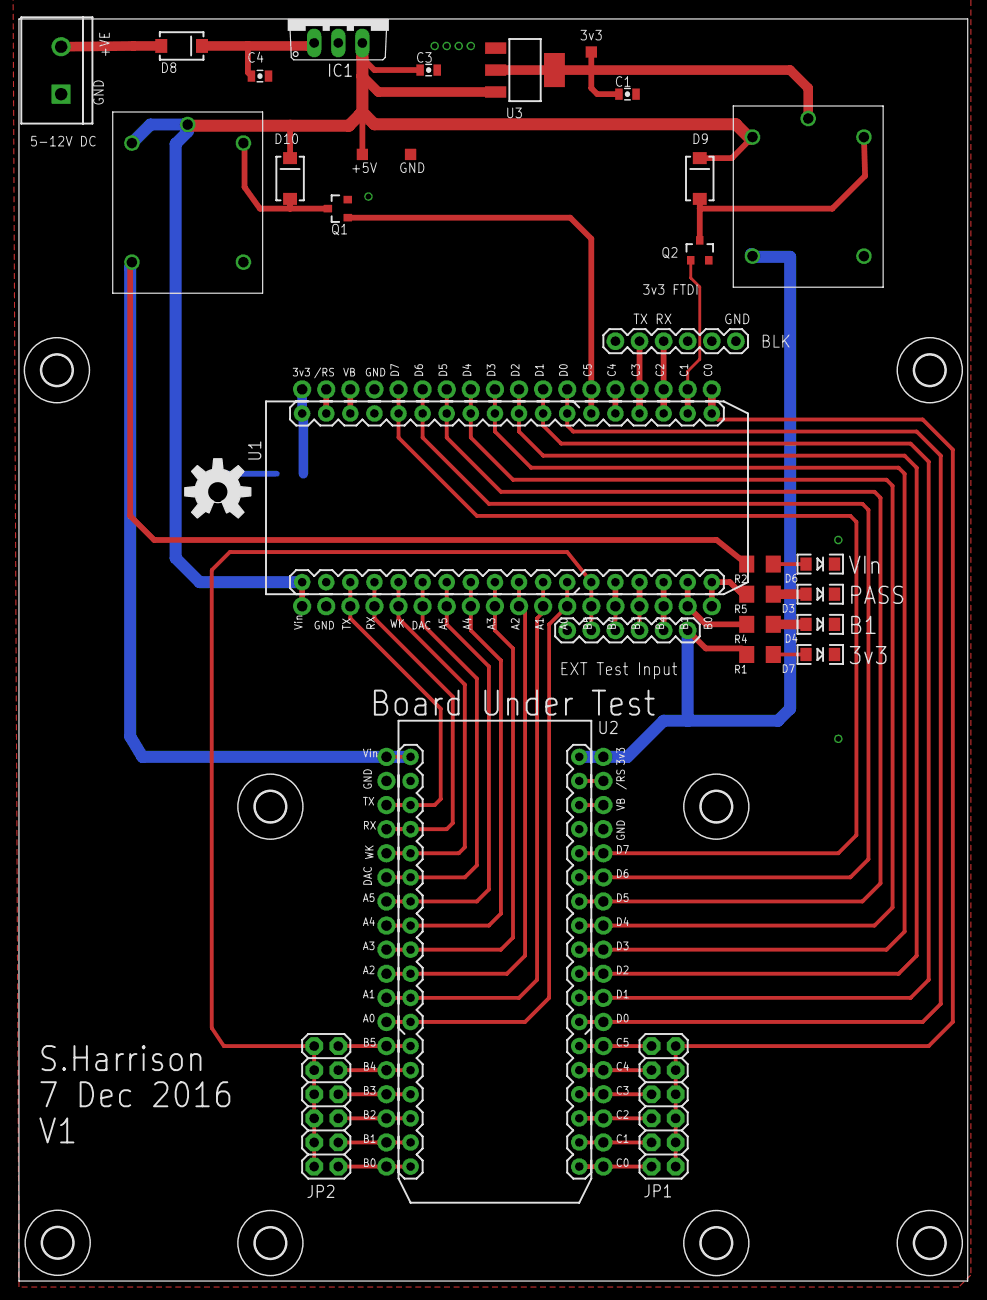
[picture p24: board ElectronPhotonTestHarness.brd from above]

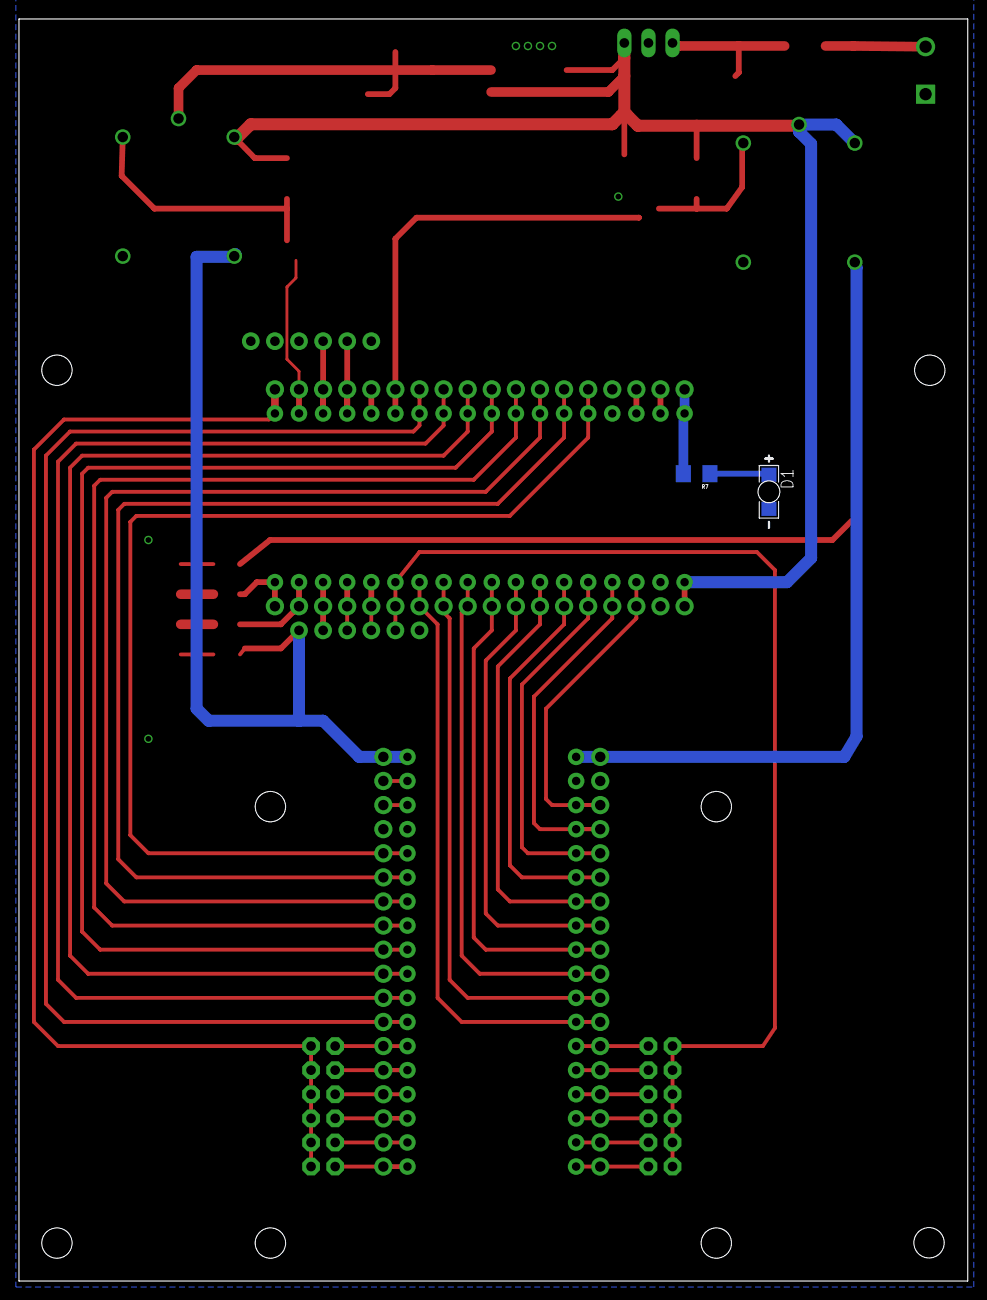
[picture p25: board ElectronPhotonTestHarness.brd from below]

Board: 2 copper layers, 100.0 x 133.0 mm, 42 parts (2 on the bottom side), 61 nets.

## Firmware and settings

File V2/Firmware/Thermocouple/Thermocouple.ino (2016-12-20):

// Electron based test harness for the Thermocouple PCB.

// Connect only when required.
SYSTEM_MODE(SEMI_AUTOMATIC);

// D0-D7 map to Photon D0-D7
// A0-A7 map to photon A0-A7

// C0 is C0-C5 option on test board.
int powerRelayPin = C1;
// Serial cable = C2 + C3
// C4 is unused.
int vinRelayPin = C5;


int passLedPin = B0;
int b1LedPin = B1; 
int extB2Pin = B2;
int extB3Pin = B3;
int extB4Pin = B4;
int extB5Pin = B5; // Shared with B0-B5 option on test board


void setup() {
    //RGB.control(true);
    RGB.color(255, 255, 255);
    
    pinMode(powerRelayPin, OUTPUT);
    digitalWrite(powerRelayPin, LOW);
    
    pinMode(vinRelayPin, OUTPUT);
    digitalWrite(vinRelayPin, LOW);
    
    pinMode(passLedPin, OUTPUT);
    digitalWrite(passLedPin, LOW);
    
    pinMode(b1LedPin, OUTPUT);
    digitalWrite(b1LedPin, HIGH);
    
    pinMode(extB2Pin, INPUT_PULLUP);
    pinMode(extB3Pin, INPUT_PULLUP);
    pinMode(extB4Pin, INPUT_PULLUP);
    pinMode(extB5Pin, INPUT_PULLUP);


    pinMode(D7, OUTPUT);
    
    Particle.connect();
    Particle.process();
    delay(2000);
    // Should force a connect.
    Particle.publish("status", "Test Harness online v0.3");

    // Indicate finished with B1 off.
    digitalWrite(b1LedPin, LOW);
}

bool isButtonPressed() {
    // Active low
    int b2Value = !digitalRead(extB2Pin);
    if (b2Value) {
        // Debounce.
        delay(250);
        b2Value = !digitalRead(extB2Pin);
    }
    return  b2Value;
}

int counter;
void loop() {
    if (isButtonPressed()) {
        beginTest();
    }
}

void beginTest() {
    digitalWrite(b1LedPin, HIGH);
    digitalWrite(passLedPin, LOW);
    Particle.publish("status", "Starting Board.T");
    digitalWrite(powerRelayPin, HIGH);
    

    RGB.color(0, 0, 255);
    
    // Do the test.
    bool passed = true;
    delay(2000);

    // OSH LED.	
    digitalWrite(D7, HIGH);
    delay(5000);
    digitalWrite(D7, LOW);

    endTest(passed);
}

void endTest(bool passed) {
    digitalWrite(powerRelayPin, LOW);
    digitalWrite(b1LedPin, LOW);
    if (passed) {
        digitalWrite(passLedPin, HIGH);
        RGB.color(0, 255, 0);
        Particle.publish("status", "BUT Passed");
    } else {
        digitalWrite(passLedPin, LOW);
        RGB.color(255, 0, 0);
        Particle.publish("status", "But Failed!");
    }
}

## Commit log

2016-12-07 Initial version of test board using Electron to run tests for a photon with additional outputs.
    [ElectronPhotonTestHarness.brd, ElectronPhotonTestHarness.sch]
2016-12-07 Tidy up for main test harness board.
    Made test top (well middle) board for Pogo pins to rest in.
    [ElectronPhotonTestHarness.brd, ElectronPhotonTestHarness.sch, ElectronPhotonTopBoard.brd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]
2016-12-07 Added name and version (post sending to DirtyPCBs)
    [ElectronPhotonTestHarness.brd]
2016-12-07 Added PCB images as generated by DirtyPCBs
2016-12-20 Added jig for thermocouple PCB.
    [ButJig.scad, ButJig.stl]
2016-12-22 Improved sizings for the Thermocouple holder jig.
    [ButJig.scad, ButJig.stl]
2017-08-07 Improved PCB holders.
    [ButJig.scad, EnvironmentV2-PushDown.stl, EnvironmentV2.stl]
2017-08-07 Refacored a little to take common calculations out of methods.
    Changed USB cutout option to go all the way to the PCB pin (i.e. as far as possible)
    Added text inset to identify the blocks.
    [ButJig.scad]
2017-08-08 Added build.bat to make all the stl's
    Split out each pcb to it's own scad file
    [ButJig.scad, ButJig.stl, EnvironmentV2-Base.stl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]
2017-08-08 Added base for test jig.
    [JigBase-UnderMountingBoard.stl, JigBase.scad, JigBase.stl]
2017-08-08 Rebuild pcb holders for test jig
    [EnvironmentV2-Base.stl, EnvironmentV2-PushDown.stl, EnvironmentV2.stl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]
2017-08-12 Improved board feet.
    [JigBase-UnderMountingBoard.stl, JigBase.scad, JigBase.stl]
2017-08-12 Added jigs for current monitor, latching relay and quad p-fets
    tweaked height that the PCB sits at for a better pogo pin contact.
    made pcb cutout in the base part deeper so the PCB can sit flush with the top of the base, and hence the push down tool sit flush with the base section.
    [BigLatchingRelay-Base.stl, BigLatchingRelay-PushDown.stl, BigLatchingRelay.scad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]

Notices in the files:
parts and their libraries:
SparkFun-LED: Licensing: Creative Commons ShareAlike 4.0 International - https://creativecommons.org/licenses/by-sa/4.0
